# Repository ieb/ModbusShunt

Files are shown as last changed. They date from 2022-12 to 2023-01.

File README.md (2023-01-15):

# Modbus Battery Sensor.

Mk1 used the ADC on an Attiny3224. Fine for voltage but not really accurate enough for low levels of current on a 75mV 100A shunt. 

This version is built arround a INA219 which is far easier to use. It speaks modbus to communicate with a modbus controller that can control if its on or not.

The controller will be a Attiny or ESP32 driving a eInk display depending. This will only be on when the boat is in service.

A BLE version was created, but in the end I felt it was overcomplicated and would need to deep sleep to avoid draining the battery.

The device speaks Modbus RTU, 9600 baud, 8N1.

# Holding registers

|| Register || type || units per bit || R/W || description ||
| 0 | int16 | serial number | R | serial number, can be written once only |
| 1 | int16 | device address | R/W | modbus unit or device address |
| 2 | int16 | A | R/W | Shunt full scale current range, default 100A |
| 3 | int16 | mV | R/W | Shunt full scale voltage, default 75mV |
| 4 | int16 | 0.1C | R/W | Temperature probe 1 offset, default 0 |
| 5 | int16 | 0.001x | R/W | Temperature probe 1 scale, default 1000 eg 1x |
| 6 | int16 | 0.1C | R/W | Temperature probe 2 offset, default 0 |
| 7 | int16 | 0.001x | R/W | Temperature probe 2 scale, default 1000 eg 1x |

# Input registers

|| Register || type || units per bit || description ||
|  0   | int16 | mV | Battery voltage |
|  1   | int16 | 0.1 A | Shunt current |
|  2   | int16 | 0.01 C | Temperature probe 1 |  
|  3   | int16 | 0.01 C | Temperature probe 2 |  
|  4   | int16 | bitmap | Lower 8 bits are Serial documented [here](https://github.com/SpenceKonde/megaTinyCore/blob/master/megaavr/extras/Ref_Serial.md#serialgetstatus) bit 8 indicates and error reading voltage, bit 9 indicates and error reading current  |
|  5   | int16 | mV | MCU Supply voltage |
|  6   | int16 | 0.1 C | MCU Temperature |
|  1000  | int16 | counter | modbus frames recieved |
|  1001   | int16 | counter | modbus frames sent |
|  1002   | int16 | counter | modbus errors recieved |
|  1003   | int16 | counter | modbus frames ignored |
|  1004   | int16 | counter | modbus errors sent |
|  1005   | int16 | counter | modbus buffer overflow |

# megaTinyCore 

This code needs megaTiny core 2.6.4 to work as there are some timing bugs that cause it to fail with the default platform IO 2.5.11 version. Upgrading is a pain as it requires installing a custom package. Installs from github fail as the layout of the source repo is wrong and missing files. 

The hacky way is to install manually as its not possible to install from a git repo due to a bug in the pio code that parses versions numbers.

		cd ~/src
		git clone https://github.com/SpenceKonde/megaTinyCore.git
		cd megaTinyCore
		git co -b 2.6.4
		mkdir ~/.platformio/packages/framework-arduino-megaavr-megatinycore@2.6.4
		cd ~/.platformio/packages/framework-arduino-megaavr-megatinycore@2.6.4
		cat << EOF > .piopm
		{"type": "tool", "name": "framework-arduino-megaavr-megatinycore", "version": "2.6.4", "spec": {"owner": "platformio", "id": 11448, "name": "framework-arduino-megaavr-megatinycore", "requirements": null, "uri": null}}
		EOF
		cat << EOF > package.json
		{
		  "name": "framework-arduino-megaavr-megatinycore",
		  "version": "2.6.4",
		  "description": "Arduino Wiring-based Framework for Microchip tinyAVR 0-series and 1-series chips (megaTinyCore)",
		  "keywords": [
		    "framework",
		    "arduino",
		    "microchip",
		    "tinyAVR"
		  ],
		  "repository": {
		    "type": "git",
		    "url": "https://github.com/ieb/megaTinyCore"
		  }
		}
		EOF
		ln -s ~/megaTinyCore/megaavr/* .
		ln -s ~/megaTinyCore/ChangeLog.md .
		ln -s ~/megaTinyCore/Installation.md .
		ln -s ~/megaTinyCore/MakeUPDIProgrammer.md .
		ln -s ~/megaTinyCore/README.md .
		ln -s ~/megaTinyCore/Wiring.md .

# ToDo

* [x] Basic implementation, with modbus, holding registers and input registers.
* [x] Implement test client
* [x] Reimplement modbus frame handling
* [x] Implement sleep mode, wake on frame
* [x] Average current and voltage over time period, eg 30s
* [x] Test frame handling of packets for other units.
* [x] Calibrate NTC sensors.
* [ ] Test write to holding registers.
* [ ] Implement current monitoring with auto scaling for different ranges using features of the INA219

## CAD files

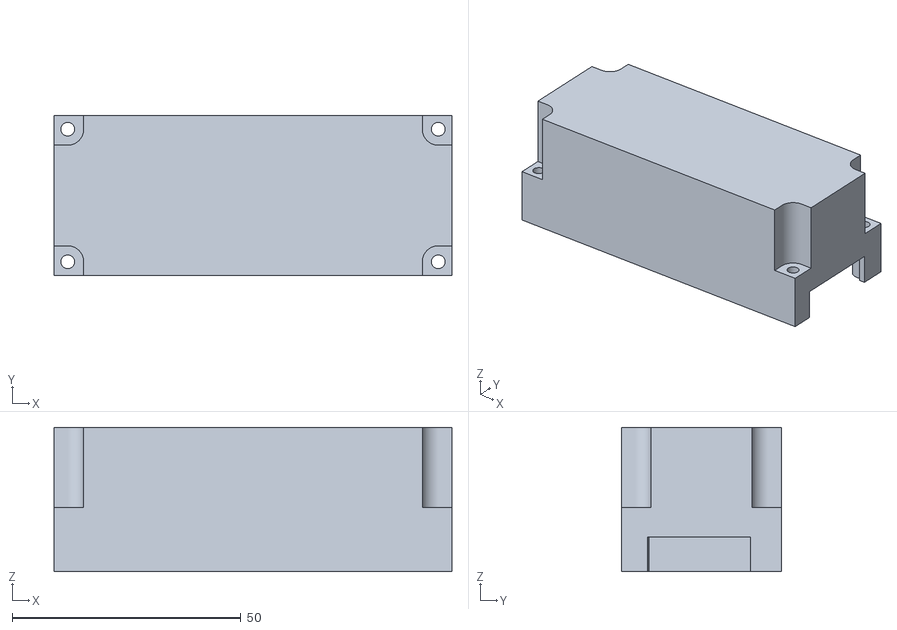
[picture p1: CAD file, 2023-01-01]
ModbusShuntLid.stl
87.0 x 35.0 x 31.5

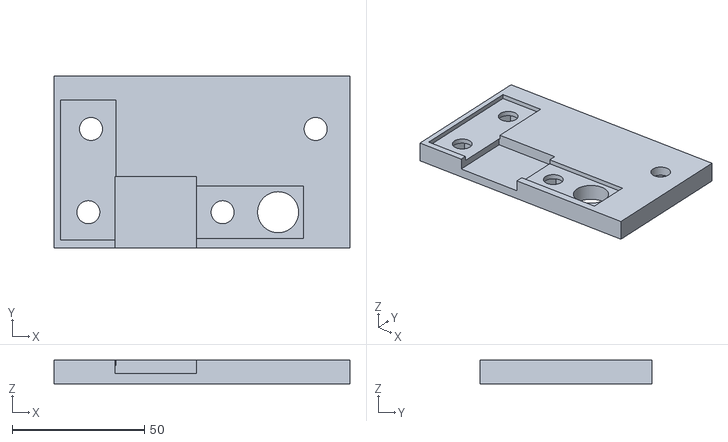
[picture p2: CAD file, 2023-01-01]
housing.stl
112.0 x 65.0 x 9.00

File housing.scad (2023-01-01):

$fn=100;
module Bolt(d=8,h=20) {
        cylinder(d=1.8*d,h=5,$fn=6);
        cylinder(d=d,h=h);
}
module shuntWithPCB() {
    difference() {
        union() {
        translate([0,0,0])
        cube([(105-43)/2,22,8]);
        translate([105-((105-43)/2),0,0])
        cube([(105-43)/2,22,8]);
        translate([0,2,4.5])
        cube([105,18,2]);
            translate([(105-60)/2,-4,8])
            cube([60,30,2]);
        }
        
        translate([(105-85)/2,11,-1])
        cylinder(d=8.7,h=20);
        translate([85+(105-85)/2,11,-1])
        cylinder(d=8.7,h=20);
    }

}

module fuse() {
    difference() {
        union() {
            translate([0,(19-16.2)/2,3])
            cube([68.8,16.2,2]);
            translate([(68.8-29.2)/2,0,0])
            cube([29.2,19,8]);
        }
        translate([(68.8-50.8)/2,19/2,-1])
            cylinder(d=8.7,h=20);
        translate([50.8+(68.8-50.8)/2,19/2,-1])
            cylinder(d=8.7,h=20);
    }
}

module boss() {
    difference() {
        union() {
        cylinder(d=8,h=7);
        cylinder(d=15,h=5);
        }
       translate([0,0,-1])
        cylinder(d=6.5,h=15);
    }
}
module boss2() {
    difference() {
        union() {
            cylinder(d=15,h=5);
        }
       translate([0,0,-1])
        cylinder(d=6.5,h=15);
    }
}

module bussbar1(l=50) {
    translate([-10,-10,0])
    difference() {
        union() {
            cube([l,20,2]);
        }
       translate([10,10,-1])
        cylinder(d=8.7,h=15);
       translate([l-10,10,-1])
        cylinder(d=8.7,h=15);
    }
}

module bussbar2(l=50) {
    translate([-10,-10,0])
    difference() {
        union() {
            cube([l,18,2]);
        }
       translate([9,9,-1])
        cylinder(d=8.7,h=15);
       translate([l-9,9,-1])
        cylinder(d=6.5,h=15);
    }
}

module housing() {
    difference() {
        union() {
            translate([-4,-4,0])
                cube([112,65,9]);
        }
        //fuse bolts
        translate([(68.8-50.8)/2,19/2,-0.1])
            Bolt(d=8.7);
        translate([50.8+(68.8-50.8)/2,19/2,-0.1])
            Bolt(d=8.7);
        translate([40-19+50.8+(68.8-50.8)/2,19/2,-0.1])
        cylinder(d=15.5,h=20);
        // shunt bolts
        translate([(105-85)/2,11+30,-0.1])
            Bolt(d=8.7);
        translate([85+(105-85)/2,11+30,-0.1])
            Bolt(d=8.7);
        // busbar 1
        translate([-1.5,-1,7])
        cube([21,53,5]);
        // busbar 2
        translate([49.5,-0.5,7])
        cube([41,20,5]);
        // fuse space
        translate([19,-10,4])
        cube([31,33,10]);
    }
}
module tube(d1=6,d2=3,h=31.5) {
    difference() {
  
     cylinder(d=d1,h=h);
     translate([0,0,-1])
     cylinder(d=d2,h=h+2);
    }
}
module cutaway(d=10,h=31.5) {
   cylinder(d=d,h=h);
   translate([-(d/2),-d,0])
     cube([d,d,h]);
   translate([-d,-d/2,0])
     cube([d,d,h]);
}
module cutawayshell(d1=6,d2=3,h=31.5) {
    difference() {
        union() {
        cube([d1,d1,h]);
        translate([d1/2,-d1,0])
            cube([d1,2*d1,h]);
        translate([-d1,d1/2,0])
            cube([2*d1,d1,h]);
        translate([-d1,-d1,h])
        cube([3*d1,3*d1,h]);
        }
        translate([0,0,-1])
        cube([d1/2,d1/2,h+1]);
//        cylinder(d=d1,h=h+1);
    }
}

module lid() {
    difference() {
        union() {
            difference() {
                union() {
                    translate([0,0,0])
                    cube([84+3,32+3,30+1.5]);
                    translate([0,4,0])
                    cube([84+3,28,30+1.5]);
                }
            translate([3/2,3/2,-0.1])
            cube([84,32,30]);
               translate([50,(34-22.5)/2,-1])
                cube([40,22.5,8.5]);
            }
            translate([3,3,0])
                    tube(d1=6,d2=3,h=30+1.5);
            translate([3,35-3,0])
                    tube(d1=6,d2=3,h=30+1.5);
            translate([87-3,3,0])
                    tube(d1=6,d2=3,h=30+1.5);
            translate([87-3,35-3,0])
                    tube(d1=6,d2=3,h=30+1.5);
            
            translate([3,3,10])
                    cutaway(d=10,h=31.5);
            translate([3,35-3,10])
                    rotate([0,0,-90])
                    cutaway(d=10,h=31.5);
            translate([87-3,3,10])
                    rotate([0,0,90])
                    cutaway(d=10,h=31.5);
            translate([87-3,35-3,10])
                    rotate([0,0,180])
                    cutaway(d=10,h=31.5);
            


        }
        translate([3,3,14])
                cylinder(d=7,h=30+1.5);
        translate([3,35-3,14])
                cylinder(d=7,h=30+1.5);
        translate([87-3,3,14])
                cylinder(d=7,h=30+1.5);
        translate([87-3,35-3,14])
                cylinder(d=7,h=30+1.5);
        
        translate([3,3,5])
                cylinder(d=3,h=30+1.5);
        translate([3,35-3,5])
                cylinder(d=3,h=30+1.5);
        translate([87-3,3,5])
                cylinder(d=3,h=30+1.5);
        translate([87-3,35-3,5])
                cylinder(d=3,h=30+1.5);
        
        translate([3,3,14])
                cutaway(d=7,h=31.5);
        translate([3,35-3,14])
                rotate([0,0,-90])
                cutaway(d=7,h=31.5);
        translate([87-3,3,14])
                rotate([0,0,90])
                cutaway(d=7,h=31.5);
        translate([87-3,35-3,14])
                rotate([0,0,180])
                cutaway(d=7,h=31.5);

        translate([5,5,0])
          rotate([0,0,180])
            cutawayshell(d1=10,h=31.5);

        translate([5,35-5,0])
          rotate([0,0,90])
            cutawayshell(d1=10,h=31.5);

        translate([87-5,5,0])
          rotate([0,0,-90])
            cutawayshell(d1=10,h=31.5);
        translate([87-5,35-5,0])
          rotate([0,0,0])
            cutawayshell(d1=10,h=31.5);


        
    }
    translate([0,7,0])
    cube([10,22,5]);
    
}
module parts() {

translate([0,30,0]) {
    translate([(105-85)/2,11,0])
    Bolt();
    translate([85+(105-85)/2,11,0])
    Bolt();
    translate([0,0,9])
    shuntWithPCB();
}
translate([0,0,6])
fuse();
translate([(68.8-50.8)/2,19/2,0])
Bolt();
translate([50.8+(68.8-50.8)/2,19/2,0])
Bolt();
/*
translate([50.8+(68.8-50.8)/2,19/2,9])
boss2();
*/
translate([(68.8-50.8)/2,19/2,7])
rotate([0,0,90])
bussbar1(l=52);

translate([50.8+(68.8-50.8)/2,21/2,7])
rotate([0,0,0])
bussbar2(l=40);

translate([40-19+50.8+(68.8-50.8)/2,19/2,3])
boss();
}
//translate([-4,24,9])
lid();
//parts();
//housing();

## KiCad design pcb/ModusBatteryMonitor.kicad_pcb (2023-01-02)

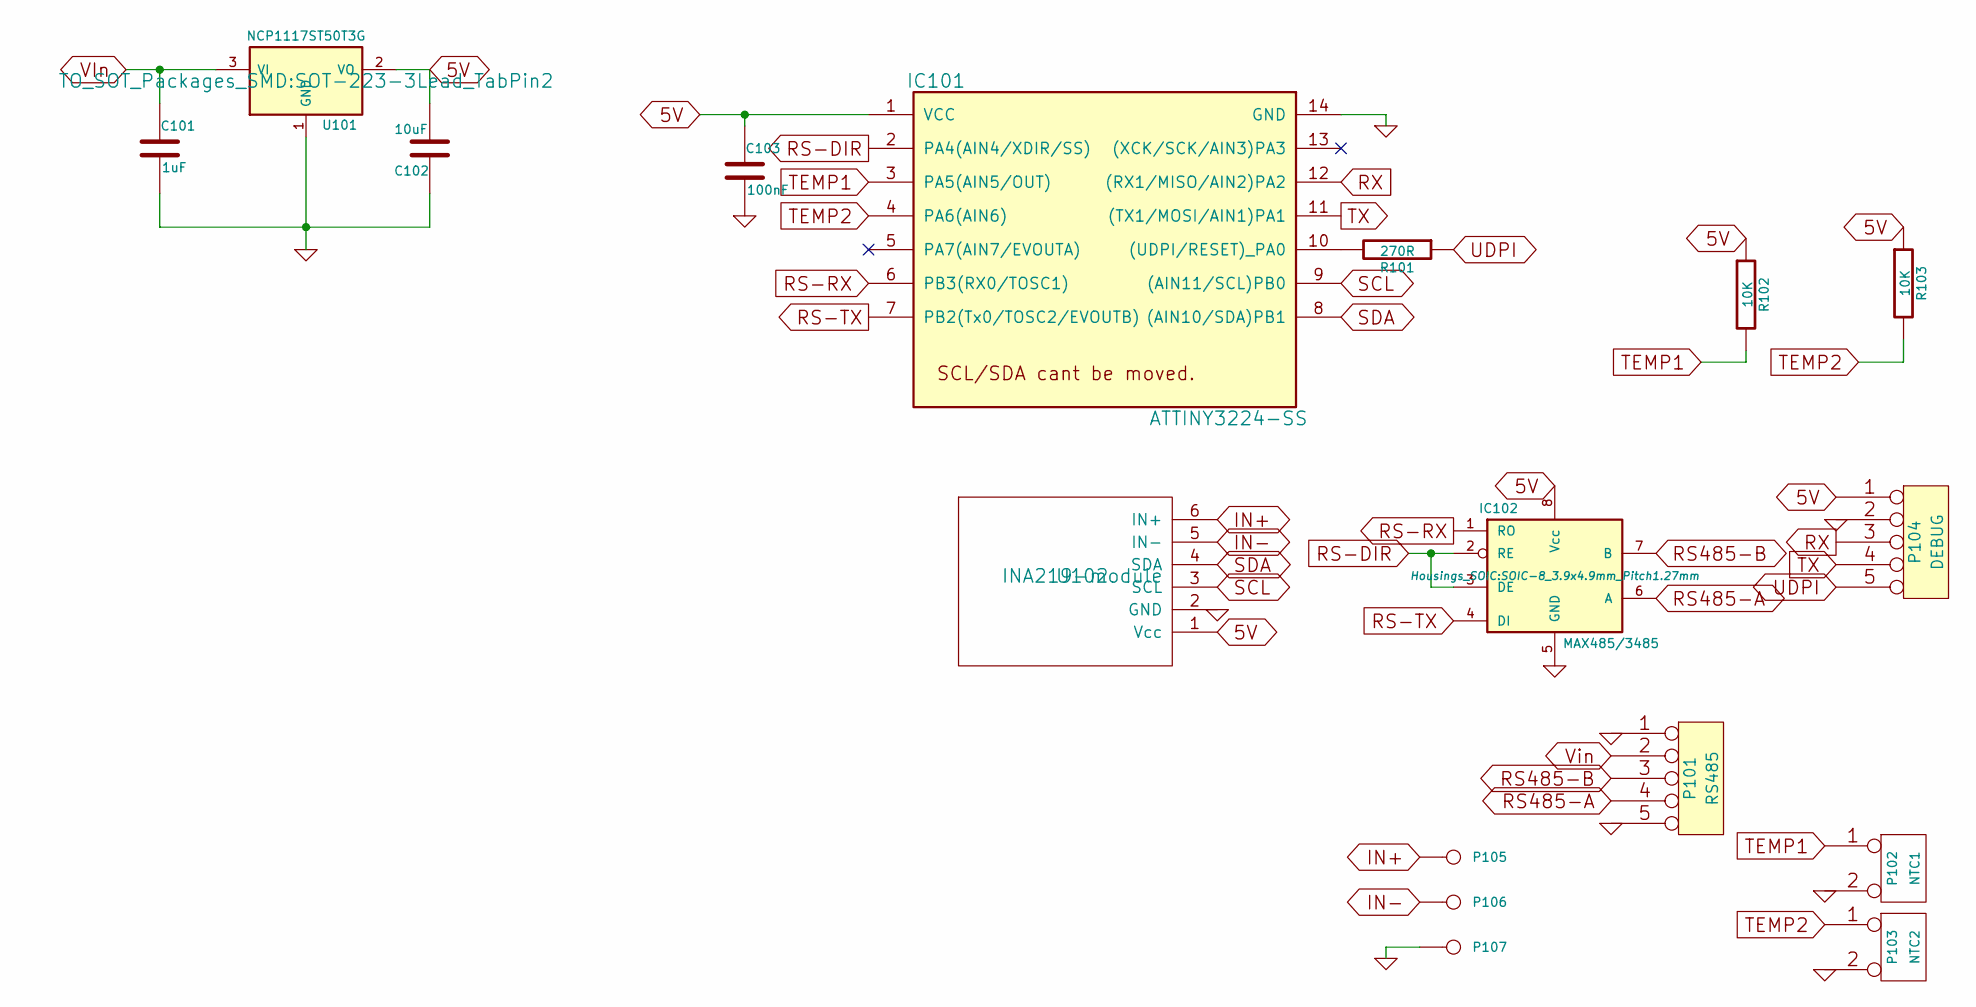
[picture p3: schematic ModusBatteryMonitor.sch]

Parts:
C101: 1uF; C_1206
C102: 10uF; C_0805
C103: 100nF; C_0805
IC101: ATTINY3224-SS; SOIC-14_3.9x8.7mm_Pitch1.27mm
IC102: MAX485/3485; SOIC-8_3.9x4.9mm_Pitch1.27mm
P101: RS485; Wago250PushSocket5way
P102: NTC1; Pin_Header_Straight_1x02
P103: NTC2; Pin_Header_Straight_1x02
P104: DEBUG; Pin_Header_Straight_1x05
P105: SHUNT+; M5Bolt
P106: SHUNT-; M5Bolt
P107: BAT-; Pin_Header_Straight_1x01
R101: 270R; R_0805
R102, R103: 10K; R_0805
U101: NCP1117ST50T3G; SOT-223-3Lead_TabPin2
U102: INA219-module; INA219Module

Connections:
5V: C102.2, C103.1, IC101.1 (VCC), IC102.8 (Vcc), P104.1, R102.1, R103.1, U101.2 (VO), U102.1 (Vcc)
GND: C101.2, C102.1, C103.2, IC101.14 (GND), IC102.5 (GND), P101.1, P101.5, P102.2 (PM), P103.2 (PM), P104.2, P107.1, U101.1 (GND), U102.2 (GND)
IN+: P105.1, U102.6 (IN+)
IN-: P106.1, U102.5 (IN-)
unnamed: IC101.10 ((UDPI/RESET)_PA0), R101.2
RS485-A: IC102.6 (A), P101.4
RS485-B: IC102.7 (B), P101.3
RS-DIR: IC101.2 (PA4(AIN4/XDIR/SS)), IC102.2 (RE), IC102.3 (DE)
RS-RX: IC101.6 (PB3(RX0/TOSC1)), IC102.1 (RO)
RS-TX: IC101.7 (PB2(Tx0/TOSC2/EVOUTB)), IC102.4 (DI)
RX: IC101.12 ((RX1/MISO/AIN2)PA2), P104.3
SCL: IC101.9 ((AIN11/SCL)PB0), U102.3 (SCL)
SDA: IC101.8 ((AIN10/SDA)PB1), U102.4 (SDA)
TEMP1: IC101.3 (PA5(AIN5/OUT)), P102.1, R102.2
TEMP2: IC101.4 (PA6(AIN6)), P103.1, R103.2
TX: IC101.11 ((TX1/MOSI/AIN1)PA1), P104.4
UDPI: P104.5, R101.1
VIn: C101.1, P101.2, U101.3 (VI)

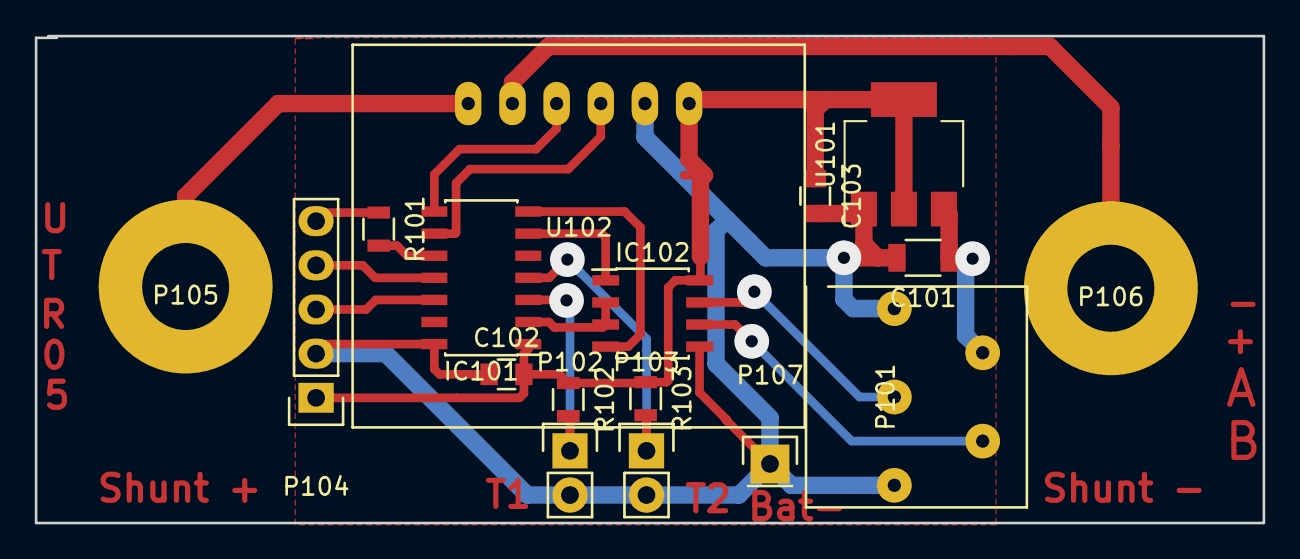
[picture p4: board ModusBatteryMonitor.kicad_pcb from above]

Board: 2 copper layers, 70.6 x 28.0 mm, 17 parts (0 on the bottom side), 18 nets.

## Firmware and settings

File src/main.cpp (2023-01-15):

#include <Arduino.h>
#include <Wire.h>

// Holding registers, used by command line, and the modbus holding 
// register class. Must be defined before including.

#define REG_SERIAL_NUMBER 0
#define REG_DEVICE_ADDRESS 1
#define REG_SHUNT_RANGE_CURRENT 2
#define REG_SHUNT_RANGE_VOLTAGE 3
#define REG_TEMPERATURE1_OFFSET 4
#define REG_TEMPERATURE1_SCALE 5
#define REG_TEMPERATURE2_OFFSET 6
#define REG_TEMPERATURE2_SCALE 7
#define NUMBER_REGISTERS 8


#include <avr/sleep.h>
#include "commandline.h"
#include "ina219.h"
#include "ntcsensor.h"
#include "modbus.h"
#include "oled.h"


extern int16_t readVoltage();
extern int16_t readCurrent();
extern int16_t readTemperature(int8_t ch);
extern int16_t readMCUVoltage();
extern int16_t readMCUTemperature();
extern CommandLine commandLine;
int16_t errorBitmap = 0x00;

// MAX485 is on RX0/TX0 Serial, TX0==PB2 pin 7, RX0=PB3 pin 6
// XDIR low to recieve, high to send on PA4 pin 4
// Debug header is on Serial1

#define rs485 Serial
#define debug Serial1


class InputRegisterImpl : public InputRegisters {
	public:
		bool hasRegister(int16_t reg) {
			return ( reg >= 0 && reg <=6 );
		}	
		int16_t getRegister(int16_t reg) {
			int16_t value = 0;
			switch(reg) {
				case 0:
					value = readVoltage();
					break;
				case 1:
					value = readCurrent();
					break;
				case 2:
					value = readTemperature(0);
					break;
				case 3: 
					value = readTemperature(1);
					break;
				case 4: 
					value = (errorBitmap & 0xFF00) | rs485.getStatus();
					break;
				case 5:
					value =  readMCUVoltage();
					break;
				case 6:
					value = 100*readMCUTemperature();
					break;

			}
			return value;
		};
};
// pins
#define TEMP_NTC1_PIN PIN_PA5  // hardware pin 3
#define TEMP_NTC2_PIN PIN_PA6  // hardware pin 4


InputRegisterImpl inputRegisters = InputRegisterImpl();
HoldingRegisters holdingRegisters = HoldingRegisters(NUMBER_REGISTERS);
Modbus modbus = Modbus(&rs485, &debug, &holdingRegisters, &inputRegisters);
Ina219 ina219(&debug);
CommandLine commandLine(&debug, &holdingRegisters, &inputRegisters);
NtcSensor ntcSensor(&debug);
Oled oled;

float averageVoltage = 0;
float averageCurrent = 0;

// must be volatile so the compiler doesnt optimnise
bool ina219Ok = true;


/*
// see https://github.com/SpenceKonde/megaTinyCore/blob/e59fc3046dd69f951497506e8f441a6818c28be5/megaavr/extras/Ref_PinInterrupts.md
// Used to detect wake up from sleep.
ISR(PORTA_PORT_vect) {
	byte flags = VPORTA.INTFLAGS;
	// wake up pin is pin PA 6
	if (flags & (1 << 6) ) {
		shouldWakeUp=true;
		VPORTA.INTFLAGS |= (1 << 6); // clear the flag, so it doesnt fire continuously.
	}
}
*/


int16_t readMCUVoltage() {
    analogReference(INTERNAL1V024);
    delayMicroseconds(100);
    int32_t vddmeasure = analogReadEnh(ADC_VDDDIV10, 12); // Take it at 12 bits
    vddmeasure *= 10; // since we measured 1/10th VDD
    int16_t returnval = vddmeasure >> 2; // divide by 4 to get into millivolts.
    if (vddmeasure & 0x02) {
        // if last two digits were 0b11 or 0b10 we should round up
        returnval++;
    }
    return returnval;
}

int16_t readMCUTemperature() {
    int8_t sigrowOffset = SIGROW.TEMPSENSE1;
    uint8_t sigrowGain = SIGROW.TEMPSENSE0;
    analogSampleDuration(128); // must be >= 32µs * f_CLK_ADC per datasheet 30.3.3.7
    analogReference(INTERNAL1V024);
    uint32_t reading = analogRead(ADC_TEMPERATURE);
    reading -= sigrowOffset;
    reading *= sigrowGain;
    reading += 0x80; // Add 1/2 to get correct rounding on division below
    reading >>= 8; // Divide result to get Kelvin
    return reading - 273; // return in C

}

void readSensors() {
		int16_t voltage = (int16_t)(1000.0*ina219.getVoltage());
		// 10mA per bit 320A  0.01*32000
	  int16_t current = (int16_t)(100*ina219.getCurrent());
		// temperature 0.01C per bit, 320C max
		int16_t temp1 = ntcSensor.getTemperature(0);
		int16_t temp2 = ntcSensor.getTemperature(1);
		uint16_t tons = millis()/1000;

		debug.print(F(" v="));debug.print(voltage);
		debug.print(F(" mV c="));debug.print(current);
		debug.print(F(" 10mA t1="));debug.print(temp1);
		debug.print(F(" 0.01C t2="));debug.print(temp2);
		debug.print(F(" 0.01C tons="));debug.print(tons);
		debug.println("");

}

void dumpModbusStatus() {
	modbus.dumpStatus();
}






void setup() {

  // Open serial communications and wait for port to open:
  debug.begin(115200);

  // try 115200, if that fails drop back to 9600 and set.


  if ( ina219.begin() != I2C_OK) {
  	ina219Ok = false;
	  debug.print(F("Failed to find INA219 chip, error:"));
	  debug.println(ina219.getError());
  }
  commandLine.begin();

  modbus.setDeviceAddress(commandLine.deviceAddress);
  modbus.begin();

  ntcSensor.addSensor(TEMP_NTC1_PIN, 0);
  ntcSensor.addSensor(TEMP_NTC2_PIN, 1);
  ntcSensor.begin();

  oled.begin();

  commandLine.diagnosticsEnabled = false;


	 if (!ina219Ok) {
	 	 debug.println(F("INA219 not responding"));
	 }
	 debug.println(F("Press h for help menu"));

	 // setup sleep mode
	 set_sleep_mode(SLEEP_MODE_STANDBY);
	 sleep_enable();

}

int16_t readVoltage() {
	return (int16_t)(1000.0*averageVoltage);;
}
int16_t readCurrent() {
	return  (int16_t)(100*averageCurrent);
}

int16_t readTemperature(int8_t ch) {
	return ntcSensor.getTemperature(ch);
}


void readShunt() {
	static unsigned long lastRead = 0;
	unsigned long now = millis();
	if ((now - lastRead) > 5000 ) {
		float voltage = ina219.getVoltage();
		float current = ina219.getCurrent();
		int16_t temp1 = readTemperature(0);
		int16_t temp2 = readTemperature(1);


		if ( lastRead == 0 ) {
				averageVoltage = voltage;
				averageCurrent = current;
		}
		lastRead = now;
		averageVoltage = averageVoltage*0.9 + voltage*0.1;
		if ( ina219.getError() != I2C_OK) {
			errorBitmap |= 0x0100;
		} else {
			errorBitmap &= 0xFDFF;
		}
		averageCurrent = averageCurrent*0.9 + current*0.1;
		if ( ina219.getError() != I2C_OK) {
			errorBitmap |= 0x0200;
		} else {
			errorBitmap &= 0xFDFF;
		}

		oled.voltage = 100*voltage;
		oled.current = 100*current;
		oled.temp1 = temp1;
		oled.temp2 = temp2;
		oled.update();

	}
}


void powerDownSleep() {
		ina219.powerDown(true);
		oled.powerDown(true);

		//USART0.STATUS &= ~(1<< 4); // enable RXSIF (Rx start frame interupt flag)
		USART0.CTRLB |= 1<<4; // set the SFDEN bit, start of frame detection.
		//USART1.STATUS &= ~(1<< 4); // enable RXSIF (Rx start frame interupt flag)
		USART1.CTRLB |= 1<<4; // set the SFDEN bit, start of frame detection.
		sleep_cpu();
		// Not required, RX clears it. USART0.CTRLB != 1<<4; // clear the SFDEN bit, start of frame detection.
		ina219.powerDown(false);
		oled.powerDown(false);

}



void loop() {
	static unsigned long lastActivity = millis();
  unsigned long now = millis(); 
  readShunt();

  if ( commandLine.checkCommand() ) {
  	lastActivity = now;  	
  }
  modbus.setDiagnostics(commandLine.diagnosticsEnabled);
  if ( modbus.readQuery() ) {
  	oled.messages++;
  	lastActivity = now;
  }
  if ( (now - lastActivity) > 60000  ) {
  	debug.println(F("sleeping"));
  	debug.flush();
  	powerDownSleep();
  	debug.println(F("wakeup"));
  	lastActivity = millis();
  }
}

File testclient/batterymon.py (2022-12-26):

#!/usr/bin/env python3

import os
import sys
import struct
import logging
from configparser import RawConfigParser
from pymodbus.client.sync import ModbusSerialClient as ModbusClient
from pymodbus.exceptions import ModbusIOException
from pymodbus.constants import Endian
from pymodbus.payload import BinaryPayloadDecoder

logger = logging.getLogger()

#logger.setLevel(logging.DEBUG)
#logging.debug("Debug enabled")

settings = RawConfigParser()
settings.read(os.path.dirname(os.path.realpath(__file__)) + '/batterymon.cfg')

port = settings.get('query', 'port', fallback='/dev/cu.wchusbserial26210')
unit = int(settings.get('battery.main', 'unit', fallback=2))
print("Using ", port, "unit", unit)
print('Setup Serial Connection... ', end='')
client = ModbusClient(method='rtu', port=port, baudrate=9600, stopbits=1, parity='N', bytesize=8, timeout=1)
client.connect()
print('Done!')

def toAscii(registers):
    b = bytearray(len(registers)*2)
    ashex = list()
    i = 0
    for x in registers:
        ashex.append('{:02x}'.format(x))
        struct.pack_into("!H",b,i,x)
        i+=2
    #print(ashex)
    #print(len(registers), b)
    return b.decode('ascii')

def dumpAsHex(registers):
    ashex = list()
    for x in registers:
        ashex.append('{:02x}'.format(x))
    print(ashex)

def packAscii(value):
    registers = list()
    abytes = value.encode('ascii')
    print(abytes)
    i = 0
    v = 0
    for b in abytes:
        v = v*256
        v = v+b
        if i == 1:
            registers.append(v)
            i = 0
            v = 0
        else:
            i += 1
    if i == 1:
        v = v*256
        registers.append(v)
    return registers
        

def dumpAsAscii(registers):
    b = bytearray(len(registers)*2)
    i = 0
    for x in registers:
        struct.pack_into("!H",b,i,x)
        i+=2
    print(len(registers), b)
    print(b.decode('ascii'))

def toInt(row):
    decoder = BinaryPayloadDecoder.fromRegisters(row.registers, Endian.Big, wordorder=Endian.Little)
    return decoder.decode_16bit_int()


# get the serial number
print("Holding Registers")
row = client.read_holding_registers(0, count=1, unit=unit)
print(row)
print("                Serial Number (0000):", toInt(row))
row = client.read_holding_registers(1, count=1, unit=20)
row = client.read_holding_registers(1, count=1, unit=unit)
print("               Device Address (0001):", toInt(row))
row = client.read_holding_registers(2, count=1, unit=20)
row = client.read_holding_registers(2, count=1, unit=unit)
print("          Shunt Current Range (0002):", toInt(row),"A")
row = client.read_holding_registers(3, count=1, unit=20)
row = client.read_holding_registers(3, count=1, unit=unit)
print("          Shunt Voltage Range (0003):", toInt(row), "mV")
row = client.read_holding_registers(4, count=1, unit=20)
row = client.read_holding_registers(4, count=1, unit=unit)
print("   Temperature Probe 1 offset (0004):", 0.1*toInt(row), "C")
row = client.read_holding_registers(5, count=1, unit=20)
row = client.read_holding_registers(5, count=1, unit=unit)
print("    Temperature Probe 1 scale (0005):", 0.001*toInt(row))
row = client.read_holding_registers(6, count=1, unit=20)
row = client.read_holding_registers(6, count=1, unit=unit)
print("   Temperature Probe 2 offset (0006):", 0.1*toInt(row), "C")
row = client.read_holding_registers(7, count=1, unit=20)
row = client.read_holding_registers(7, count=1, unit=unit)
print("    Temperature Probe 2 scale (0007):", 0.001*toInt(row))


print("Input Registers")

row = client.read_input_registers(0, count=1, unit=20)
row = client.read_input_registers(0, count=1, unit=unit)
print("                 Voltage (0000):", 0.001*toInt(row), "V")
row = client.read_input_registers(1, count=1, unit=20)
row = client.read_input_registers(1, count=1, unit=unit)
print("                 Current (0001):", 0.01*toInt(row), "A")
row = client.read_input_registers(2, count=1, unit=20)
row = client.read_input_registers(2, count=1, unit=unit)
print("            Temperature1 (0002):", 0.01*toInt(row), "C")
row = client.read_input_registers(3, count=1, unit=20)
row = client.read_input_registers(3, count=1, unit=unit)
print("            Temperature2 (0003):", 0.01*toInt(row), "C")
row = client.read_input_registers(4, count=1, unit=20)
row = client.read_input_registers(4, count=1, unit=unit)
print("            Error bitmap (0004):", '{:016b}'.format(row.registers[0]))
print("                                 ||||||||||||||||")
print("                                 |||||||||||||||^0 serial data written (should be 1)")
print("                                 ||||||||||||||^-1 half duplex enabled")
print("                                 |||||||||||||^--2 serial parity error (clears on read)")
print("                                 ||||||||||||^---3 serial frame error (clears on read)")
print("                                 |||||||||||^----4 serial autobaud enabled")
print("                                 ||||||||||^-----5 serial autoboaud sync enabled, if both 4&5 there was a bad sync")
print("                                 |||||||||^------6 serial overflow ring buffer error - chars dropped, read more frequently, self clears on read")
print("                                 ||||||||^-------7 serial overflow hardware error - chars dropped, irqs disable for too long, self clears on read")
print("                                 |||||||^--------i2c read voltage error")
print("                                 ||||||^---------i2c read current error")
print("                                 |||||^----------unused")
print("                                 ||||^-----------unused")
print("                                 |||^------------unused")
print("                                 ||^-------------unused")
print("                                 |^--------------unused")
print("                                 ^---------------unused")
row = client.read_input_registers(5, count=1, unit=20)
row = client.read_input_registers(5, count=1, unit=unit)
print("             MCU Voltage (0005):", 0.001*toInt(row), "V")
row = client.read_input_registers(6, count=1, unit=20)
row = client.read_input_registers(6, count=1, unit=unit)
print("         MCU Temperature (0006):", 0.1*toInt(row), "C")
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

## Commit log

2022-12-21 Initial version
    [ModusBatteryMonitor.kicad_pcb, ModusBatteryMonitor.sch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]
2022-12-24 Modbus tested and working for read.
    [batterymon.cfg]
2022-12-26 Added better Modbus RTU frame handling, sleep and tests
2023-01-01 Made housing
    [ModbusShuntLid.stl, ModusBatteryMonitor.kicad_pcb, ModusBatteryMonitor.sch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]
2023-01-02 Fixed NtC sensors and adjusted LUT
    [ModusBatteryMonitor.kicad_pcb, ModusBatteryMonitor.sch]
2023-01-15 Added OLED display
    [ModusBatteryMonitor.sch]
